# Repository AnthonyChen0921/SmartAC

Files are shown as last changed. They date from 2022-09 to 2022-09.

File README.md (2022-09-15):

This Project uses a low-cost methodology to convert a traditional AC to a smart AC.

Basic logic:
If human body detection module sense empty room, it return 0 reading to the port.
The program start to do the counting towards 10min / any time that you want, it could be customized.

<br/>

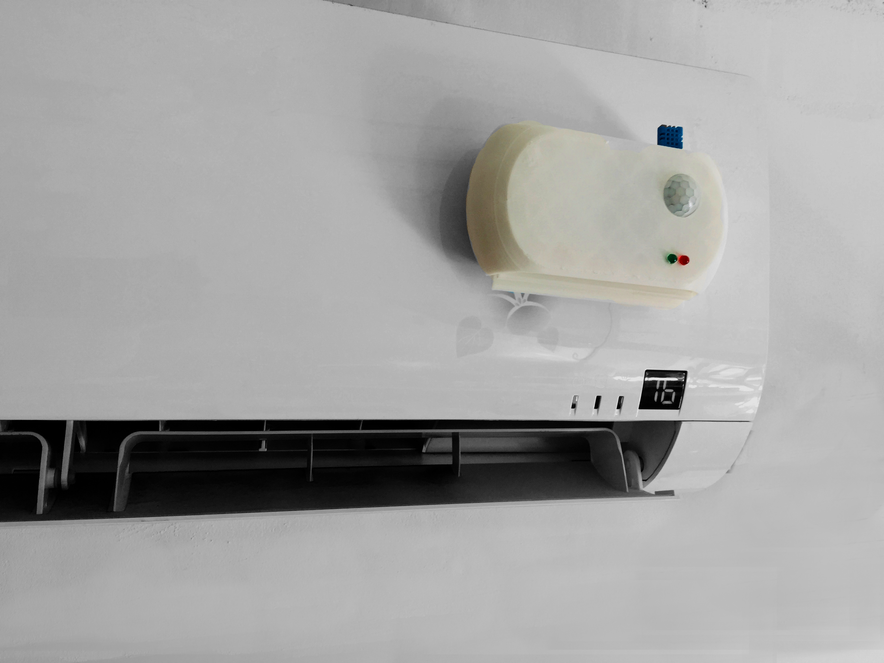
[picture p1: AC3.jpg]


<br/>

How my device connect to the AC:
Use the infra RED receptor, connected to the port, and use the controller you have (I did for Gree and Mitsubishi) to take in the array sended by the controllers.
Then store the arrays into database. Send them when the logic designed is met.

Sample signal for Gree:

CLOSE:
Raw: (139) 8956,4408,700,1592,700,500,700,496,700,500,700,1592,700,1592,700,500,700,496,700,1556,740,496,700,476,724,1592,700,496,704,496,700,500,700,496,700,500,700,500,700,496,676,524,700,496,704,1588,704,496,676,524,700,1592,700,500,700,496,700,500,700,1592,700,500,700,1592,700,496,700,500,700,1592,700,500,700,19856,700,496,704,496,700,496,704,476,720,500,700,496,704,496,700,500,700,496,700,476,724,496,704,496,700,496,704,1564,728,496,704,496,700,496,700,500,704,496,700,496,704,496,700,500,700,496,700,500,700,496,704,496,704,496,700,496,700,1592,704,1592,700,1592,700,496,704,

<br/>

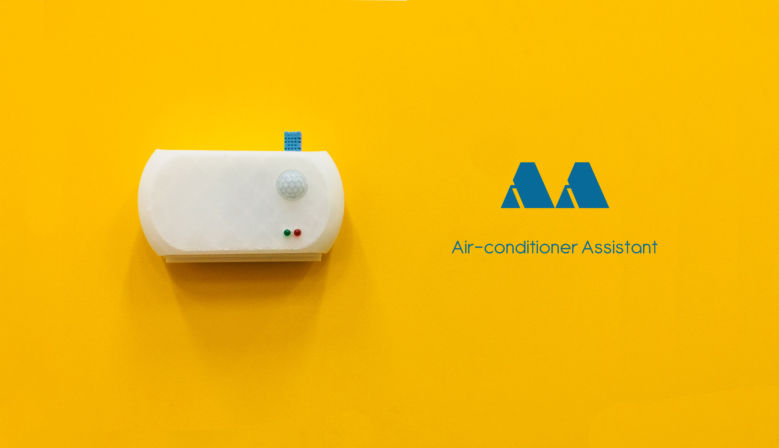
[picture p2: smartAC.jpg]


<br/>

For Mitsubishi:
open:
Raw: (583) 3428,1700,440,1252,448,1252,448,412,448,416,444,416,448,1252,444,416,448,412,452,1252,444,1252,448,416,444,1252,448,412,452,412,448,1252,448,1252,444,416,448,1252,444,1252,448,416,448,416,444,1252,444,420,444,412,452,1252,444,416,448,416,444,416,448,416,448,416,444,416,448,416,444,416,448,416,444,416,448,416,444,416,448,416,448,412,520,344,448,416,444,416,448,416,444,416,524,340,448,1248,448,416,448,412,448,416,444,416,448,416,448,1248,448,1256,444,412,452,1252,444,392,472,1252,444,1252,448,416,520,1180,444,416,444,416,448,416,448,412,448,416,448,1252,444,1252,448,416,444,1252,448,1248,448,416,448,412,452,1248,448,1252,448,412,448,416,448,1248,448,412,452,1252,444,392,472,416,448,412,448,416,448,416,444,416,448,416,444,416,448,416,448,412,448,416,448,412,448,416,448,412,448,416,448,416,444,416,520,344,444,416,452,412,448,416,444,416,448,376,484,416,448,416,444,416,448,416,448,412,448,416,448,412,448,416,448,412,448,416,448,416,444,420,444,412,448,416,448,1248,448,420,444,416,448,412,448,416,448,416,444,420,444,416,444,420,444,416,448,412,448,416,448,412,448,416,448,412,448,416,448,416,448,412,448,412,452,412,448,1252,444,420,444,392,472,416,444,1252,448,1252,444,416,448,416,448,15752,3476,1644,448,1248,448,1252,448,416,444,416,448,412,452,1248,448,412,448,416,448,1252,448,1248,448,416,448,1248,520,344,448,416,444,1256,444,1252,448,412,448,1252,448,1248,448,380,484,412,452,1248,448,416,448,416,444,1252,448,408,452,416,448,412,448,412,452,416,500,364,444,412,504,336,472,412,452,412,504,360,504,360,496,364,448,416,500,360,500,364,448,416,444,416,500,360,500,364,504,1192,448,416,500,360,448,412,504,364,444,416,500,1200,448,1248,448,416,448,1252,444,416,448,1248,448,1252,448,412,452,1248,448,416,500,360,448,416,500,360,500,364,500,1200,500,1196,448,412,452,1248,500,1200,448,412,448,416,500,1196,452,1176,576,356,504,360,504,1156,488,412,504,1196,500,364,500,360,500,360,504,360,500,360,500,364,500,360,504,360,500,364,496,364,500,360,500,364,504,360,500,364,496,364,500,364,496,280,672,248,524,364,500,360,500,364,500,364,500,360,504,360,496,364,500,364,496,368,496,364,500,364,496,344,520,364,496,364,500,364,496,368,472,388,472,392,472,392,492,1204,496,340,524,364,472,388,496,368,496,368,472,388,496,368,472,388,472,368,496,388,476,384,476,388,476,388,472,388,476,388,472,388,476,388,472,388,476,388,472,1228,472,388,476,388,472,388,476,1224,472,1228,472,388,472,392,472

No need to mention, this is a huge array.

At first i store them in the main memory of arduino uno, but they are really too big. So i use const int to store them to flash memory, which is enough for more than 50 lines for Gree. But some good companies in AC developer more complex infrared red signal, taking more space in my memory. Maybe could use Wifi module to store them in the online databse such as Mongodb, so that the device can pull those data when necessary. Plus, connecting to the wifi allows remote start, set timer, and more advanced features. Which is a to-do for this project.

<br/>

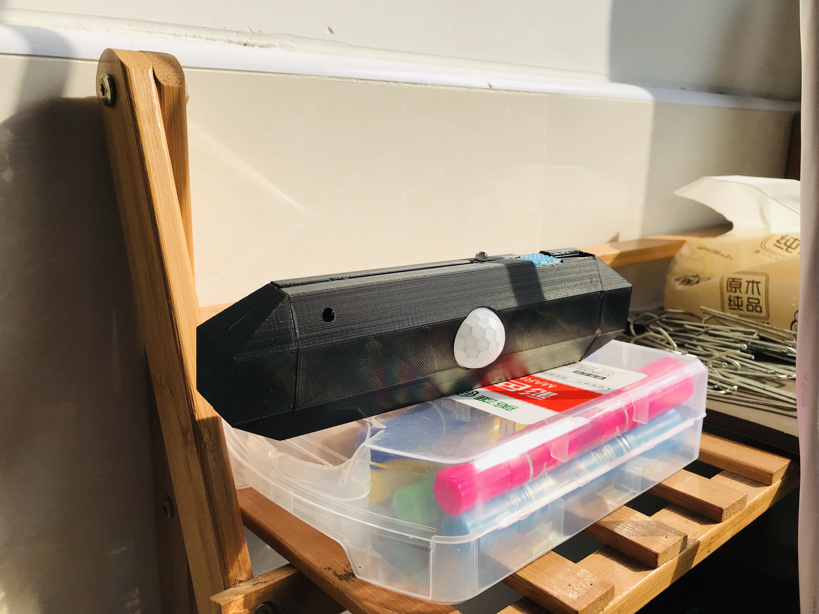
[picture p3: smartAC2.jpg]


<br/>

I designed 2 gen of outshell. Both 3D printable.

<br/>

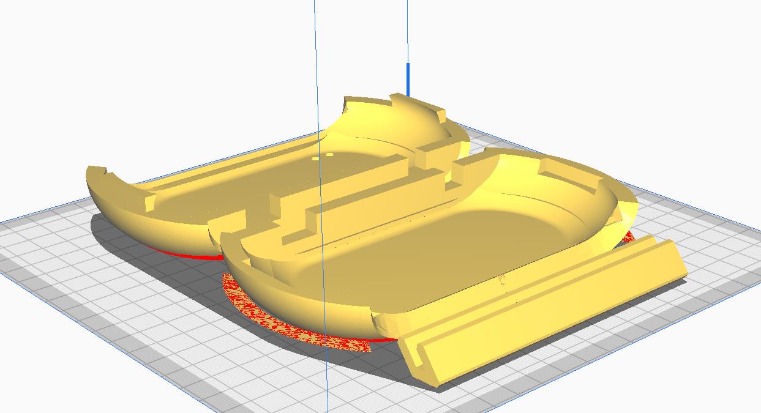
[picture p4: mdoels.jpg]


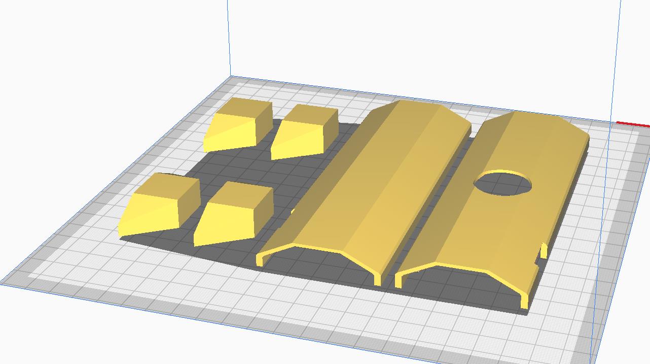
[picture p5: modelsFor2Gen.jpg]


<br/>

**Abstract**

With the development of the intelligent home, many smart homes that are convenient for people's life are gradually stepping into people's lives. The so-called smart home refers to the integration of facilities related to home life by using generic cabling technology, network communication technology, security protection technology, automatic control technology, and audio and video technology to build an efficient management system of residential facilities and family schedule, improve the safety, convenience, comfort, and artistry of home, and achieve an environment-friendly and energy-saving living environment. Suppose the air conditioner can be made intelligent, for example. In that case, it will automatically turn off half an hour after people leave the air-conditioned room. They no longer worry about forgetting to turn off the air conditioner when they are in a hurry to go to work or in public places such as classrooms, and people lack the awareness of saving electricity. Therefore, I want to develop an intelligent air conditioning control system to facilitate user operation and save energy, environmental protection, and money.

**1 Infrared module**
One part is to use an infrared transmitter and receiver, which can easily make the air conditioner reach the effect of temperature regulation and switch. The other part uses HC-SR501. HC-SR501 is a human body infrared sensing module that can sense the presence of people within the range. When someone is in the air-conditioned room, the air conditioner can continue to operate. As long as people leave the room for a particular time, they can send a shutdown signal through the front infrared transmitter to shut down the air conditioner to save power.
**2 Temperature module**
DHT11 was used in this experiment for its advantages in many aspects. DHT11 has an ultra-small volume, low power consumption, fast response speed, and accurate temperature measurement and humidity. The temperature and humidity information can be directly transferred to Arduino to perform the next step.

**3 System Installation**

**3.1 Program Construction**
Because Arduino is used as the microcontroller, Arduino IDE is used as the programming software in this experiment.

**① Air conditioning infrared code**
The circuit connected with the infrared receiver and Arduino is used to receive the infrared signals of opening, closing, and temperature regulating on the remote controller of the air conditioner. The 229 lengths of array infrared signal read are programmed to facilitate proper control of the air conditioner in the future.

**②  Infrared human body sense coding**
HC-SR501 can detect any human body and small animals within the range of 0-7 meters. With this feature, we can specify that it can perform any other temperature regulation and switch on/off the air conditioner when a person is detected. When a person leaves an air-conditioned room for more than 10 minutes, the air conditioner will automatically turn off to save electricity. That is more practical in public places. For example, in an empty classroom, students may think that the school's electricity uses the air conditioner and that it is the responsibility of others to turn off the air conditioner without any action. In the code, a counter is used; when the time without any infrared signal input reaches a specific value, the air conditioner will be turned off automatically.

@copyright Anthony Chen

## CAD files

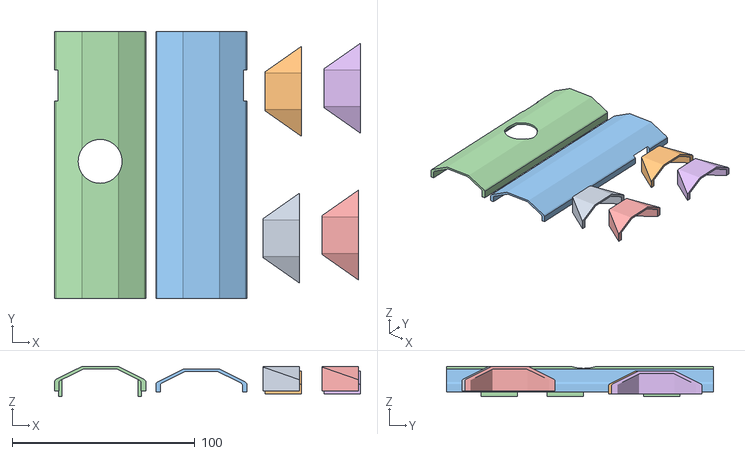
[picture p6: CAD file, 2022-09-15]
HUSK.stl
167.6 x 146.0 x 16.5

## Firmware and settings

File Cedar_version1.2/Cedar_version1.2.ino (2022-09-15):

#include <IRremote.h>                  // 引用 IRRemote 函式库
#include <avr/pgmspace.h>
#include <avr/wdt.h>             // flash数据存储
#include <VoiceRecognition.h>    // 语音识别函数库
VoiceRecognition Voice;

// DATA BASE Infra
const PROGMEM unsigned int rawCodes_ac_16c[229]={3124,3004,3132,4408,564,1632,588,512,592,1632,584,472,632,512,592,1628,592,1628,592,508,592,488,616,512,592,508,592,512,592,508,592,512,616,1604,592,508,592,508,596,508,616,1608,588,512,592,508,592,512,616,484,620,484,616,488,612,488,616,488,592,512,612,488,616,484,616,1608,612,488,616,484,616,1604,616,484,620,484,620,484,616,484,620,480,620,488,616,484,616,488,616,1604,616,488,612,484,620,484,616,484,620,484,616,488,616,488,612,484,620,484,616,488,616,488,616,484,616,488,616,484,616,484,620,1604,616,484,616,484,620,484,616,488,616,488,612,488,616,484,616,488,616,488,616,484,616,488,616,484,616,488,616,436,664,456,648,484,616,488,616,488,612,492,612,484,616,488,616,484,616,488,616,484,616,484,620,488,616,484,616,488,616,484,616,488,616,488,612,484,620,484,616,488,616,484,616,488,616,484,616,464,640,488,588,512,592,512,612,484,596,508,592,508,596,1628,592,512,592,1628,592,512,588,516,588,1632,584,516,588,1632,588,1632,588
};  // 16c code
const PROGMEM unsigned int rawCodes_ac_26c[229]={3144,3028,3104,4408,580,1640,584,516,584,1636,584,520,556,548,584,1636,556,1664,584,516,584,1632,588,516,588,1636,584,516,588,520,580,512,592,1636,584,516,584,520,584,516,584,1636,584,516,588,468,636,496,604,516,588,540,560,544,560,516,584,516,588,480,620,512,592,476,624,1640,580,500,604,512,588,1636,584,520,584,516,588,516,584,516,588,516,584,516,584,520,584,520,584,1520,700,516,584,520,584,512,588,516,588,512,588,520,584,516,588,512,588,516,588,512,588,512,588,520,584,516,584,516,588,512,592,1632,588,472,628,520,584,516,588,516,584,516,584,520,584,516,588,516,584,544,560,512,588,520,584,516,560,516,612,496,604,492,612,520,584,480,620,516,608,496,584,520,604,472,628,496,608,496,608,496,608,492,608,492,612,520,580,468,636,496,608,448,652,492,612,492,608,496,608,520,584,488,612,496,608,492,612,492,608,488,616,492,608,516,588,440,664,488,612,492,608,492,556,1620,604,1664,556,1664,556,548,608,1612,556,568,532,1664,556,548,556
};  // 26c code
const PROGMEM unsigned int rawCodes_ac_op[229]={3096,3032,3124,4388,560,1664,556,572,532,1660,560,544,556,548,556,1660,556,1684,540,544,556,548,556,548,552,548,556,548,556,540,560,544,560,1660,560,548,552,552,552,548,556,1660,560,544,556,548,556,548,556,544,612,516,532,508,648,492,612,488,612,492,612,492,608,496,608,1608,556,548,612,492,608,1612,608,492,612,488,612,488,616,492,608,488,616,492,608,496,604,496,608,1608,616,488,612,492,608,496,608,520,584,492,608,496,604,500,604,496,604,492,612,488,616,492,612,488,612,496,604,496,608,492,612,1612,608,492,608,496,608,492,612,488,616,492,608,492,612,492,608,468,636,492,612,484,616,492,612,492,608,492,612,488,612,492,612,488,612,496,608,496,608,488,612,492,556,544,616,484,616,492,612,492,608,472,632,488,612,488,612,492,612,488,616,492,608,492,612,492,608,496,608,472,628,488,616,488,612,520,584,492,608,496,608,492,608,488,612,472,632,1612,612,492,608,1612,608,492,612,1612,608,424,676,496,604,1620,604,1612,608,1612,612,1600,564
};  // open code
const PROGMEM unsigned int rawCodes_ac_cl[229]={3096,3040,3124,4408,584,1612,612,484,616,1608,556,548,556,548,552,1660,560,1668,552,552,624,500,528,524,576,520,584,548,556,540,560,552,552,572,528,552,552,548,552,548,556,1664,556,548,552,552,624,476,552,548,556,548,552,552,552,524,648,472,560,572,604,472,556,548,556,1688,528,572,532,572,528,552,552,548,552,552,552,552,548,544,560,548,552,552,552,548,556,544,556,1664,556,544,560,548,552,548,624,480,624,476,556,544,556,548,628,472,556,552,548,544,560,572,608,468,556,548,628,476,552,504,600,1664,556,548,552,548,556,572,528,552,552,548,552,552,552,548,552,576,528,548,552,544,560,544,556,552,552,540,560,548,556,552,548,552,552,552,548,552,552,548,552,548,644,460,552,552,552,548,552,544,560,552,548,552,552,548,552,552,552,548,552,548,556,572,532,540,560,548,552,552,552,548,552,544,560,548,556,548,552,576,528,572,528,552,552,504,600,1664,552,552,552,1668,552,548,552,552,552,548,552,576,528,1668,552,1668,552,552,548,1672,548
};  // close code


int n;
int k;   

int count = 0;
int count_close = 0;
int time_p = 0;

const int buttonstate_op = 8; // open button
const int buttonstate_on = 6;

int val_op = 0;  // Check state
int val_on = 0;  // Check state
int old_val_on = 0; 
int state = 0; 

int val = 0;            //存储获取到的PIR数值
int PIR_sensor = A0;    //指定PIR模拟端口 A0

#include <dht11.h>        // load temp and moisture detector
dht11 DHT11;
#define DHT11PIN 7
void(* resetFunc) (void) = 0; //制造重启命令
 
IRsend irsend;                          // 定义 IRsend 物件来发射红外线讯号
 

void setup()
{
  pinMode(PIR_sensor, INPUT);   //设置PIR模拟端口为输入模式
  pinMode(buttonstate_op,INPUT);
  pinMode(buttonstate_on,OUTPUT);

  pinMode(3, OUTPUT);   
  digitalWrite(3, HIGH);   // 点亮LED测试（需通过手机摄像模式观察） 你可以开始插个led灯来观察led灯是否亮，如果亮就可以换成红外线发射灯了
  delay(3000);             // 等待3秒
  digitalWrite(3, LOW);    // 结束测试

  Serial.begin(9600);    // 温度传感

    Voice.init();//初始化VoiceRecognition模块   
    Voice.addCommand("kai ji",0);                     //添加指令，参数1:指令内容，参数2：指令标签（可重复）
    Voice.addCommand("kai kong tiao",0); 
                                                   //如“北京”和“首都”代表同样含义，则可共用标签。无返回
    Voice.addCommand("guan ji",1);                    //添加指令，参数（指令内容，指令标签（可重复））
    Voice.addCommand("guan kong tiao",1); 
    Voice.start();                                 //开始识别
}


 
void loop()
{
 
  while(1)
  {  
  
  
  
  
    val_op = digitalRead(buttonstate_op);
    if(val_op==LOW)
    {
     digitalWrite(buttonstate_on,HIGH); 
    
      switch(Voice.read())                //判断识别内容，在有识别结果的情况下Voice.Read()会返回该指令标签，否则返回-1
    {
      case 0://若是指令“kai”
      Serial.println("kaiji");
      unsigned int shuzu_op[229];
      for (k = 0; k<229; k++)
    {
      shuzu_op[k] = pgm_read_word_near(rawCodes_ac_op + k);
    }
      irsend.sendRaw(shuzu_op,229, 38);
      Serial.println("open code sended");
      break;
      case 1://若是指令“guan”
      Serial.println("guanji");
      unsigned int shuzu_cl[229];
      for (k = 0; k<229; k++)
    {
      shuzu_cl[k] = pgm_read_word_near(rawCodes_ac_cl + k);
    }
      irsend.sendRaw(shuzu_cl,229, 38);
      Serial.println("close code sended");
      break;   
    }
    wdt_reset();
  
    
    
    val = analogRead(PIR_sensor);                        //DHT11温控模块，获取温湿度
    Serial.println();
    int chk = DHT11.read(DHT11PIN);
    Serial.print("Read sensor: ");
    Serial.print("Humidity (%): ");
    Serial.println((float)DHT11.humidity, 2);
    Serial.print("Temperature (oC): ");
    Serial.println((float)DHT11.temperature, 2);
    delay(2000);          

  digitalWrite(buttonstate_on,LOW);

    
    if(val > 300)       // 人体红外传感数值  有人一般为600+ 没人则为0
    {
    Serial.print("count =");  // count值测试，决定温度区间
    Serial.print((int)count);
    count_close = 0;  // 红外感应关机条件，在有人的时候清零
    time_p = 0;       // 红外感应关机条件，计数器模块，可调节，在val值变化时清零
    
    if((float)DHT11.temperature >= 32.0 and count == 0)
     {
      unsigned int shuzu_16c[229];
    for (k = 0; k<229; k++)
  {
    shuzu_16c[k] = pgm_read_word_near(rawCodes_ac_16c + k);
  }
    irsend.sendRaw(shuzu_16c,229, 38);
    Serial.println("16c code sended");
    count = 5;         //count变为5，不再满足=0条件，使16度代码只发送一次
    //测试count值
    Serial.print("count ="); 
    Serial.print((int)count);
     }
     

    if((float)DHT11.temperature <= 26.0 and count == 0)
    { 
      unsigned int shuzu_26c[229];
    for (k = 0; k<229; k++)
  {
    shuzu_26c[k] = pgm_read_word_near(rawCodes_ac_26c + k);
  }
    irsend.sendRaw(shuzu_26c,229, 38);
    Serial.println("26c code sended");
    count = 3;
    Serial.print("count =");
    Serial.print((int)count);
   }

    if (((float)DHT11.temperature > 26.0) and ((float)DHT11.temperature < 32.0))
      {
      count = 0;
      Serial.print("count =");
      Serial.print((int)count);
      }
    }
    else
    {
      
      if(count_close == 0 and time_p > 75){
      unsigned int shuzu_cl[229];
    for (k = 0; k<229; k++)
  {
    shuzu_cl[k] = pgm_read_word_near(rawCodes_ac_cl + k);
  }
    irsend.sendRaw(shuzu_cl,229, 38);
    Serial.println("Close code sended");
      
      count_close = 5;
      }
      time_p = time_p + 1;
      delay(2000);
      Serial.print("time = ");
      Serial.print(time_p);
      }
    }
      else if(val_op==HIGH)  //------------------------------------------------------
      {
        digitalWrite(buttonstate_on,LOW); 
        //send warm coode
    
      switch(Voice.read())                //判断识别内容，在有识别结果的情况下Voice.Read()会返回该指令标签，否则返回-1
    {
      case 0://若是指令“kai”
      Serial.println("kaiji");
      unsigned int shuzu_op[229];
      for (k = 0; k<229; k++)
    {
      shuzu_op[k] = pgm_read_word_near(rawCodes_ac_op + k);
    }
      irsend.sendRaw(shuzu_op,229, 38);
      Serial.println("open code sended");
      break;
      case 1://若是指令“guan”
      Serial.println("guanji");
      unsigned int shuzu_cl[229];
      for (k = 0; k<229; k++)
    {
      shuzu_cl[k] = pgm_read_word_near(rawCodes_ac_cl + k);
    }
      irsend.sendRaw(shuzu_cl,229, 38);
      Serial.println("close code sended");
      break;   
    }
    wdt_reset();
  
    
    
    val = analogRead(PIR_sensor);                        //DHT11温控模块，获取温湿度
    Serial.println();
    int chk = DHT11.read(DHT11PIN);
    Serial.print("Read sensor: ");
    Serial.print("Humidity (%): ");
    Serial.println((float)DHT11.humidity, 2);
    Serial.print("Temperature (oC): ");
    Serial.println((float)DHT11.temperature, 2);
    delay(2000);          


    
    if(val > 300)       // 人体红外传感数值  有人一般为600+ 没人则为0
    {
    Serial.print("count =");  // count值测试，决定温度区间
    Serial.print((int)count);
    count_close = 0;  // 红外感应关机条件，在有人的时候清零
    time_p = 0;       // 红外感应关机条件，计数器模块，可调节，在val值变化时清零
    
    if((float)DHT11.temperature <= 15.0 and count == 0)
     {
      unsigned int shuzu_16c[229];
    for (k = 0; k<229; k++)
  {
    shuzu_16c[k] = pgm_read_word_near(rawCodes_ac_16c + k);
  }
    irsend.sendRaw(shuzu_16c,229, 38);
    Serial.println("16c code sended");
    count = 5;         //count变为5，不再满足=0条件，使16度代码只发送一次
    //测试count值
    Serial.print("count ="); 
    Serial.print((int)count);
     }
     

    if((float)DHT11.temperature >= 24.0 and count == 0)
    { 
      unsigned int shuzu_26c[229];
    for (k = 0; k<229; k++)
  {
    shuzu_26c[k] = pgm_read_word_near(rawCodes_ac_26c + k);
  }
    irsend.sendRaw(shuzu_26c,229, 38);
    Serial.println("26c code sended");
    count = 3;
    Serial.print("count =");
    Serial.print((int)count);
   }

    if (((float)DHT11.temperature > 15.0) and ((float)DHT11.temperature < 24.0))
      {
      count = 0;
      Serial.print("count =");
      Serial.print((int)count);
      }
    }
    else
    {
      
      if(count_close == 0 and time_p > 75){
      unsigned int shuzu_cl[229];
    for (k = 0; k<229; k++)
  {
    shuzu_cl[k] = pgm_read_word_near(rawCodes_ac_cl + k);
  }
    irsend.sendRaw(shuzu_cl,229, 38);
    Serial.println("Close code sended");
      
      count_close = 5;
      }
      time_p = time_p + 1;
      delay(2000);
      Serial.print("time = ");
      Serial.print(time_p);
      }
      }
  
  } 
}

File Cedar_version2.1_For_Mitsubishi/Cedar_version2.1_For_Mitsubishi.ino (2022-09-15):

#include <IRremote.h>                  // 引用 IRRemote 函式库
#include <avr/pgmspace.h>
#include <avr/wdt.h>             // flash数据存储
#include <VoiceRecognition.h>    // 语音识别函数库
VoiceRecognition Voice;

// DATA BASE Infra
const PROGMEM unsigned int rawCodes_ac_16c[583]={3444,1676,468,1228,468,1232,468,396,468,392,468,372,492,1204,492,396,468,392,468,1232,468,1228,472,392,468,1204,492,396,468,396,468,1228,472,1228,468,392,472,1228,468,1228,472,392,472,388,472,1228,468,396,468,368,492,1232,468,392,472,392,468,396,468,392,468,396,468,392,468,396,468,392,472,364,496,392,472,392,468,392,472,392,468,392,472,392,468,396,468,392,472,392,468,392,472,392,468,1228,472,392,468,392,472,368,492,372,492,392,468,1232,468,1228,472,392,468,1228,472,392,468,392,472,392,468,396,468,392,468,372,492,392,472,392,468,392,472,392,468,1232,468,1228,468,392,472,1228,468,1208,492,392,472,392,468,1228,468,1232,468,396,468,392,468,1228,472,392,468,1232,468,368,496,392,468,392,472,392,468,392,472,392,468,396,468,392,472,392,468,392,472,392,468,392,472,392,468,396,468,392,468,396,468,392,472,392,468,392,468,396,468,392,472,392,468,392,472,392,468,396,468,392,472,388,472,392,468,396,468,392,472,392,468,392,472,392,468,392,472,392,468,396,468,392,468,1232,468,392,468,396,468,392,472,392,468,392,472,368,492,396,468,392,468,348,516,368,492,396,468,392,472,364,496,396,468,392,468,392,472,392,468,392,472,392,472,392,468,1232,468,1228,468,396,468,392,468,1232,468,392,468,372,492,15728,3448,1676,468,1228,468,1232,468,372,492,392,468,392,472,1228,468,396,468,392,468,1232,468,1228,468,396,468,1228,472,392,468,392,472,1228,468,1232,468,368,492,1232,468,1228,472,392,468,396,468,1228,468,348,516,392,468,1232,468,392,468,372,492,392,472,392,468,392,472,392,468,392,472,392,468,392,472,392,472,392,468,392,472,392,468,392,468,396,468,392,472,392,468,392,472,392,468,348,516,1228,468,396,468,392,468,396,468,396,464,396,468,1232,468,1228,468,396,468,1228,468,396,468,392,468,396,468,392,472,392,468,392,472,368,492,396,468,368,492,396,468,1228,468,1232,468,396,468,1228,468,1208,492,392,468,396,468,1228,468,1232,468,392,468,396,468,1196,504,368,492,1228,472,392,468,396,468,392,468,396,468,392,468,396,468,396,468,392,468,396,468,392,468,396,468,392,468,340,528,388,472,388,472,392,468,396,468,392,472,392,468,396,468,392,468,396,468,392,468,396,468,368,496,392,468,392,472,392,468,396,468,392,468,396,468,392,468,396,468,356,504,396,468,392,468,396,468,1232,468,392,468,392,468,396,468,396,468,392,468,396,468,392,468,396,468,392,468,396,468,396,464,396,468,396,468,392,468,396,468,392,468,396,468,392,468,368,496,396,464,1232,468,1232,464,396,468,396,464,1236,464,396,468,392,468
};  // 16c code
const PROGMEM unsigned int rawCodes_ac_27c[583]={3448,1672,468,1232,468,1228,468,396,468,392,468,396,468,1232,468,392,468,348,516,1228,468,1208,492,392,468,1232,468,392,472,392,468,1228,468,1232,468,396,468,1228,468,1232,468,396,464,396,468,1232,468,392,468,396,468,1228,468,396,468,392,468,396,468,396,464,396,468,392,468,396,468,392,472,392,468,396,464,396,472,392,464,396,468,372,492,392,468,396,468,396,468,392,468,392,472,392,468,1232,464,396,468,396,468,392,468,396,468,392,468,1232,468,1232,468,392,468,1232,468,372,488,1232,468,1232,468,392,468,1232,464,396,468,396,464,396,468,368,496,392,468,1232,468,1228,472,392,468,1232,468,1228,468,396,468,392,468,1232,468,1228,472,392,468,392,468,1232,468,368,496,1228,468,396,468,392,468,396,468,392,468,396,468,396,464,396,468,396,464,396,468,396,468,392,468,396,468,392,468,396,468,392,472,392,468,392,472,392,468,396,468,392,468,396,468,392,468,396,468,392,468,372,492,392,472,372,488,396,468,392,468,396,464,396,472,392,468,392,472,392,468,396,468,392,468,396,464,1232,468,396,464,396,468,396,468,392,468,396,464,396,468,396,468,392,468,396,468,396,468,392,468,396,468,392,468,396,468,396,464,396,468,396,468,392,468,396,468,1208,488,396,468,392,472,392,468,1232,468,1228,468,396,468,392,468,15732,3444,1676,464,1236,468,1232,464,396,468,392,468,396,468,1228,468,396,468,392,472,1228,468,1232,464,396,472,1228,464,396,468,396,468,1232,468,1228,468,396,464,1232,468,1232,468,392,468,396,468,1228,468,396,468,392,468,1232,468,396,468,392,468,396,468,392,468,396,468,392,468,396,468,392,468,396,468,396,468,392,468,396,468,392,468,392,472,392,468,396,468,392,468,372,492,368,492,396,468,1232,468,392,468,396,468,368,492,396,468,392,472,1228,468,1228,472,392,468,1232,468,392,468,1232,468,1228,468,396,468,1228,468,396,468,396,464,396,468,372,492,392,468,1232,468,1232,464,396,468,1232,464,1232,468,372,492,392,468,1232,468,1232,464,396,468,392,468,1232,468,396,464,1232,468,392,472,392,468,396,468,392,468,396,468,392,468,396,468,396,464,396,468,396,468,368,492,396,468,392,468,396,468,392,468,396,468,392,468,396,468,396,468,392,468,396,468,392,468,396,468,392,468,396,468,392,468,396,468,396,464,396,468,396,468,392,468,396,464,372,492,396,468,392,472,392,468,396,464,1232,468,392,468,396,468,396,464,376,488,396,468,392,468,396,468,392,468,396,468,392,468,396,468,364,500,392,468,396,468,392,468,396,468,396,464,372,492,392,472,1228,468,392,468,396,468,396,464,1232,468,1232,468,392,468,396,468
};  // 27c code
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
